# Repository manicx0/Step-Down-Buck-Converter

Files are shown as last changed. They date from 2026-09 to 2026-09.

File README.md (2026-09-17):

# LM5116 Wide-Range Synchronous Buck Converter

A variable-output synchronous buck converter designed around the Texas Instruments
LM5116 controller, capable of delivering 3 V to ~41 V output at up to 8 A from
a 45 V input rail. Designed as an open-source hardware project for industrial,
bench-supply, and automotive applications.

> ⚠️ **Status: Work In Progress — not yet validated on hardware.**
> Schematic is complete and under review. PCB layout not yet started.

---

## Specifications

| Parameter | Value |
|---|---|
| Input Voltage | Up to 45 V |
| Output Voltage | 3 V – ~41 V (continuously variable) |
| Maximum Output Current | 8 A |
| Switching Frequency | ~200 kHz |
| Control Method | Emulated peak current mode |
| Topology | Synchronous Buck |
| Controller IC | Texas Instruments LM5116MH/NOPB |

---

## Key Design Decisions

### Variable Output
Output voltage is set by a feedback divider on the FB pin (pin 9).
RFB1 (R4 = 1.21 kΩ) is fixed. RFB2 is implemented as a 50 kΩ potentiometer (R3)
in series with a 1.78 kΩ fixed resistor (R30), which hard-limits the minimum
output to 3 V even when the pot is at 0 Ω.
VOUT = 1.215 V × (1 + RFB2 / RFB1)

At RFB2 = 1.78 kΩ → VOUT = 3.01 V (minimum)
At RFB2 = 51.78 kΩ → VOUT ≈ 53 V (capped by VIN in practice)

### Slope Compensation (RRAMP)
For output voltages above 7.5 V, the LM5116 datasheet (Section 7.2.2.16)
requires a resistor from the RAMP pin to VCC to add slope compensation and
prevent subharmonic oscillation. R15 = 120 kΩ is connected between
pin 5 (RAMP) and pin 16 (VCC), sized for a nominal output of ~24 V.

### Emulated Current Ramp Capacitor

CRAMP = (gm × L) / (A × RS)
= (5 µA/V × 18 µH) / (10 V/V × 10 mΩ)
= 900 pF → 1 nF COG selected (C3)

### MOSFET Selection
Both high-side (Q3) and low-side (Q4) use the Infineon BSC070N10NS5,
a 100 V / 70 mΩ N-channel MOSFET in a TO-252 package. The 100 V rating
provides adequate margin over the 45 V input accounting for switching
transients and ringing.

Key references from the LM5116 datasheet (SNVS499I):
- Section 6.3.6 — Ramp generator and RRAMP justification
- Section 7.2.2.11 — Output voltage divider equations
- Section 7.2.2.16 — Comprehensive equations for VOUT > 7.5 V
- Section 7.4 — Layout guidelines

---

## ⚠️ Warnings & Limitations

- Maximum output voltage is bounded by the 450 ns forced HO off-time:
  `VOUT_max = VIN × (1 − 450 ns × fSW)`. At 45 V input and 200 kHz,
  this is approximately 41 V — not a true 45 V output.
- VCCX (pin 17) must be connected to GND if the external bias feature
  is not used. Leaving it floating causes unpredictable VCC behavior.
- This design has not yet been validated on hardware.
  Use at your own risk in any safety-critical application.
- High voltage and high current. Always verify polarity of electrolytic
  output capacitors before powering on.

---

## Acknowledgements

- Texas Instruments LM5116 datasheet (SNVS499I) — design procedure
  and equations throughout Section 7
- TI WEBENCH Power Designer for cross-checking component values
- Infineon BSC070N10NS5 datasheet for MOSFET loss calculations

---

## License

This project is released under the **CERN Open Hardware Licence Version 2 –
Weakly Reciprocal (CERN-OHL-W-2.0)**.

You are free to study, modify, and distribute this hardware design.
If you distribute modified versions, you must use the same licence.

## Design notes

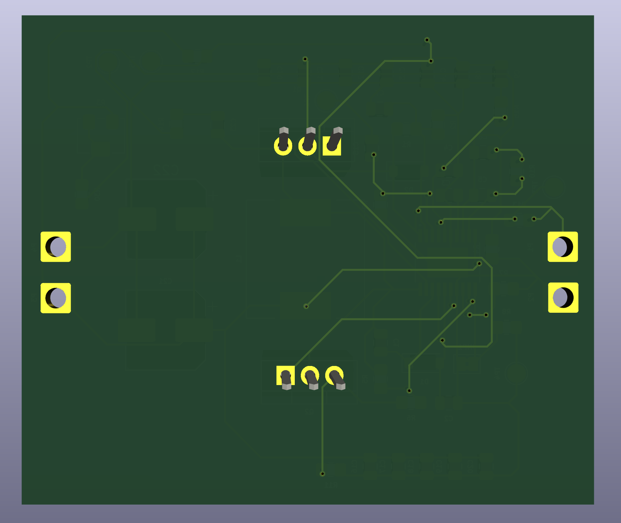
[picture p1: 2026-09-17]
hardware/exports/pcb-back.png

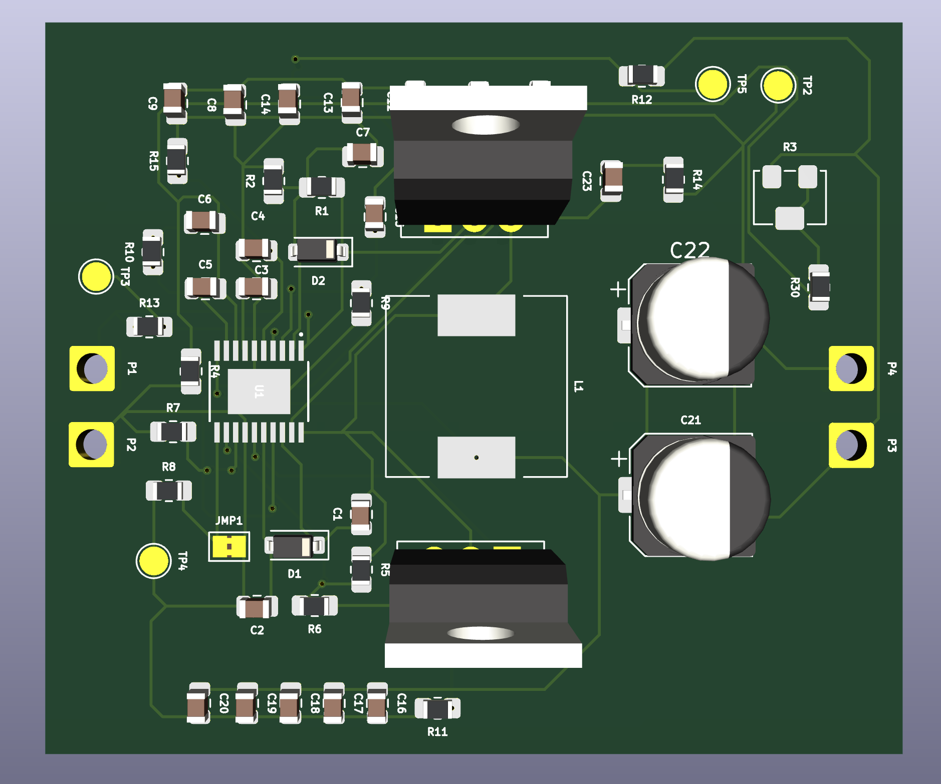
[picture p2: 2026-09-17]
hardware/exports/pcb-front.png

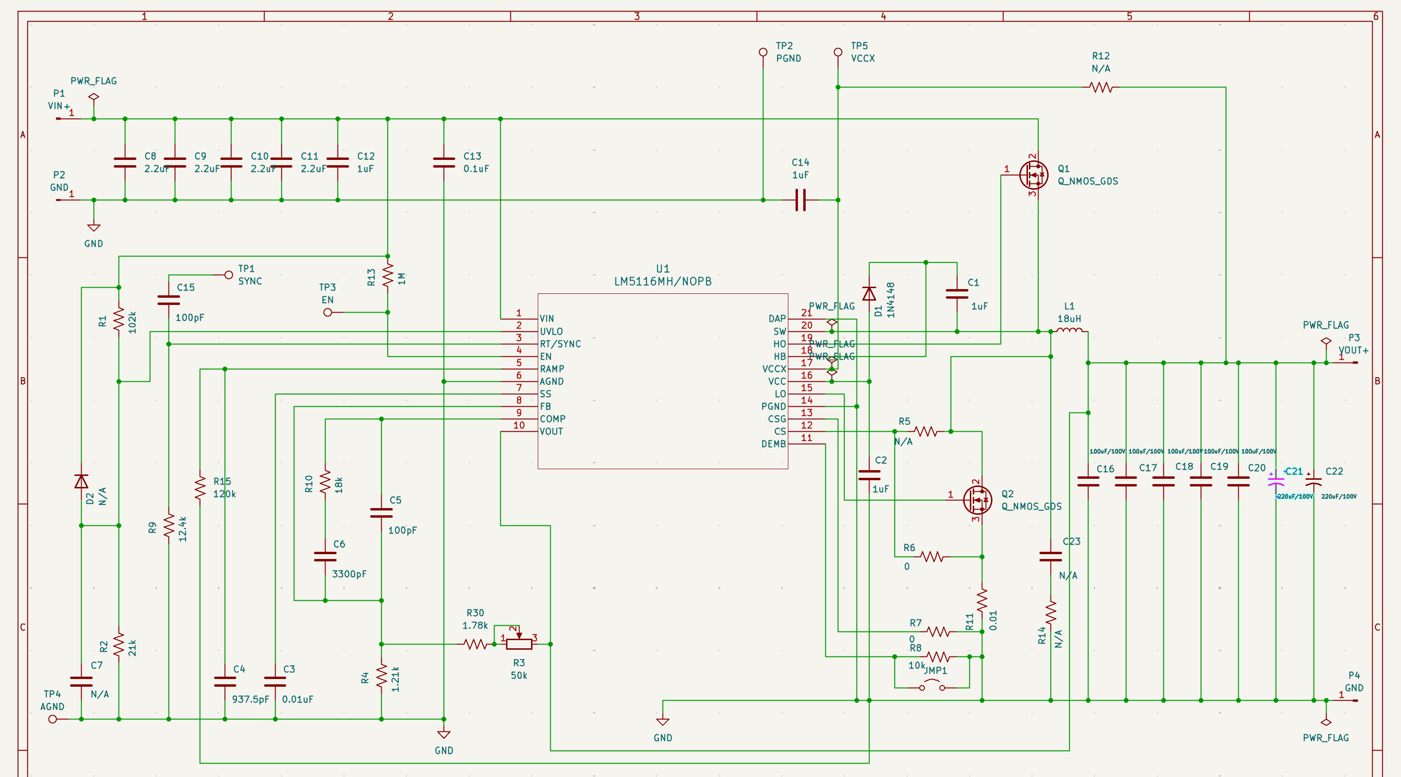
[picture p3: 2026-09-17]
hardware/exports/schematic.png

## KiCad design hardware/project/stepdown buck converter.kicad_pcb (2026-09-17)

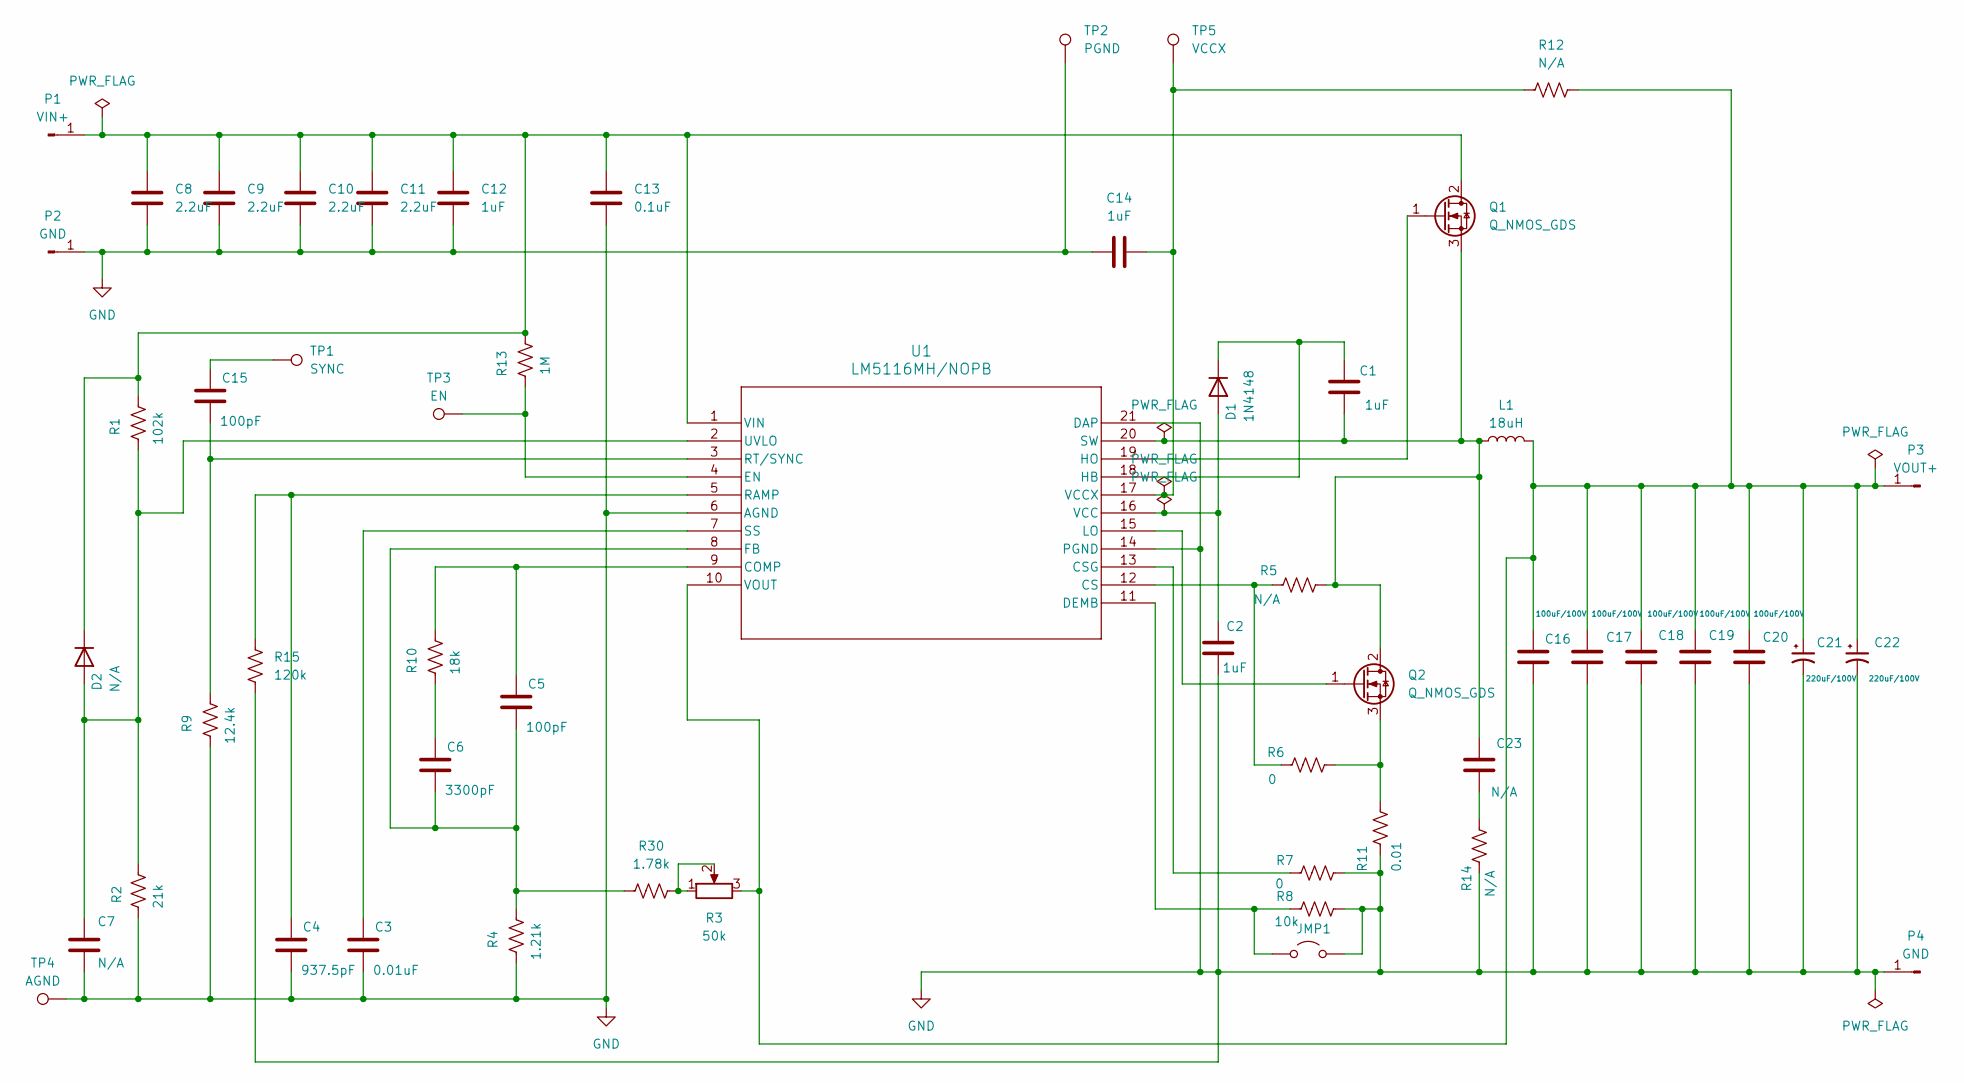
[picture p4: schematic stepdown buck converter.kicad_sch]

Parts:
C1, C2, C12, C14: 1uF; C_0805_2012Metric
C3: 0.01uF; C_0805_2012Metric
C4: 937.5pF; C_0805_2012Metric
C5, C15: 100pF; C_0805_2012Metric
C6: 3300pF; C_0805_2012Metric
C7, C23: N/A; C_0805_2012Metric
C8, C9, C10, C11: 2.2uF; C_0805_2012Metric
C13: 0.1uF; C_0805_2012Metric
C16, C17, C18, C19, C20: 100uF/100V; C_0805_2012Metric
C21, C22: 220uF/100V; CP_Elec_8x5.4
D1: 1N4148; D_SOD-123
D2: N/A; D_SOD-123
JMP1: SolderJumper-2_P1.3mm_Bridged2Bar_Pad1.0x1.5mm
L1: 18uH; L_12x12mm_H6mm
P1: VIN+; SolderWire-1.5sqmm_1x01_D1.7mm_OD3mm
P2, P4: GND; SolderWire-1.5sqmm_1x01_D1.7mm_OD3mm
P3: VOUT+; SolderWire-1.5sqmm_1x01_D1.7mm_OD3mm
Q1, Q2: Q_NMOS_GDS; TO-220-3_Vertical
R1: 102k; R_0805_2012Metric_Pad1.20x1.40mm_HandSolder
R2: 21k; R_0805_2012Metric_Pad1.20x1.40mm_HandSolder
R3: 50k; Potentiometer_Bourns_3214W_Vertical
R4: 1.21k; R_0805_2012Metric_Pad1.20x1.40mm_HandSolder
R5, R12, R14: N/A; R_0805_2012Metric_Pad1.20x1.40mm_HandSolder
R6, R7: 0; R_0805_2012Metric_Pad1.20x1.40mm_HandSolder
R8: 10k; R_0805_2012Metric_Pad1.20x1.40mm_HandSolder
R9: 12.4k; R_0805_2012Metric_Pad1.20x1.40mm_HandSolder
R10: 18k; R_0805_2012Metric_Pad1.20x1.40mm_HandSolder
R11: 0.01; R_0805_2012Metric_Pad1.20x1.40mm_HandSolder
R13: 1M; R_0805_2012Metric_Pad1.20x1.40mm_HandSolder
R15: 120k; R_0805_2012Metric_Pad1.20x1.40mm_HandSolder
R30: 1.78k; R_0805_2012Metric_Pad1.20x1.40mm_HandSolder
TP1: SYNC; TestPoint_Pad_D2.0mm
TP2: PGND; TestPoint_Pad_D2.0mm
TP3: EN; TestPoint_Pad_D2.0mm
TP4: AGND; TestPoint_Pad_D2.0mm
TP5: VCCX; TestPoint_Pad_D2.0mm
U1: LM5116MH/NOPB; MXA20A_TEX

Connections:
GND: C2.2, C3.2, C4.2, C7.2, C8.1, C9.1, C10.1, C11.1, C12.1, C13.1, C14.1, C16.2, C17.2, C18.2, C19.2, C20.2, C21.2, C22.2, JMP1.2 (B), P2.1 (Pin_1_1), P4.1 (Pin_1_1), R2.2, R4.2, R7.1, R8.1, R9.2, R11.2, R14.2, R15.2, TP2.1 (1_1), TP4.1 (1_1), U1.6 (AGND), U1.14 (PGND), U1.21 (DAP)
unnamed: C6.1, R10.2
unnamed: C15.1, TP1.1 (1_1)
unnamed: C23.2, R14.1
unnamed: C2.1, D1.2 (A), U1.16 (VCC)
unnamed: C1.1, D1.1 (K), U1.18 (HB)
unnamed: C7.1, D2.2 (A), R1.2, R2.1, U1.2 (UVLO)
unnamed: C8.2, C9.2, C10.2, C11.2, C12.2, C13.2, D2.1 (K), P1.1 (Pin_1_1), Q1.2 (D), R1.1, R13.1, U1.1 (VIN)
unnamed: JMP1.1 (A), R8.2, U1.11 (DEMB)
unnamed: C16.1, C17.1, C18.1, C19.1, C20.1, C21.1, C22.1, L1.2, P3.1 (Pin_1_1), R3.3, R12.1, U1.10 (VOUT)
unnamed: Q1.1 (G), U1.19 (HO)
unnamed: C1.2, C23.1, L1.1, Q1.3 (S), Q2.2 (D), R5.1, U1.20 (SW)
unnamed: Q2.1 (G), U1.15 (LO)
unnamed: Q2.3 (S), R6.1, R11.1
unnamed: R3.1, R3.2, R30.2
unnamed: C5.1, R10.1, U1.9 (COMP)
unnamed: R5.2, R6.2, U1.12 (CS)
unnamed: R7.2, U1.13 (CSG)
unnamed: R13.2, TP3.1 (1_1), U1.4 (EN)
unnamed: C5.2, C6.2, R4.1, R30.1, U1.8 (FB)
unnamed: C4.1, R15.1, U1.5 (RAMP)
unnamed: C15.2, R9.1, U1.3 (RT/SYNC)
unnamed: C3.1, U1.7 (SS)
unnamed: C14.2, R12.2, TP5.1 (1_1), U1.17 (VCCX)

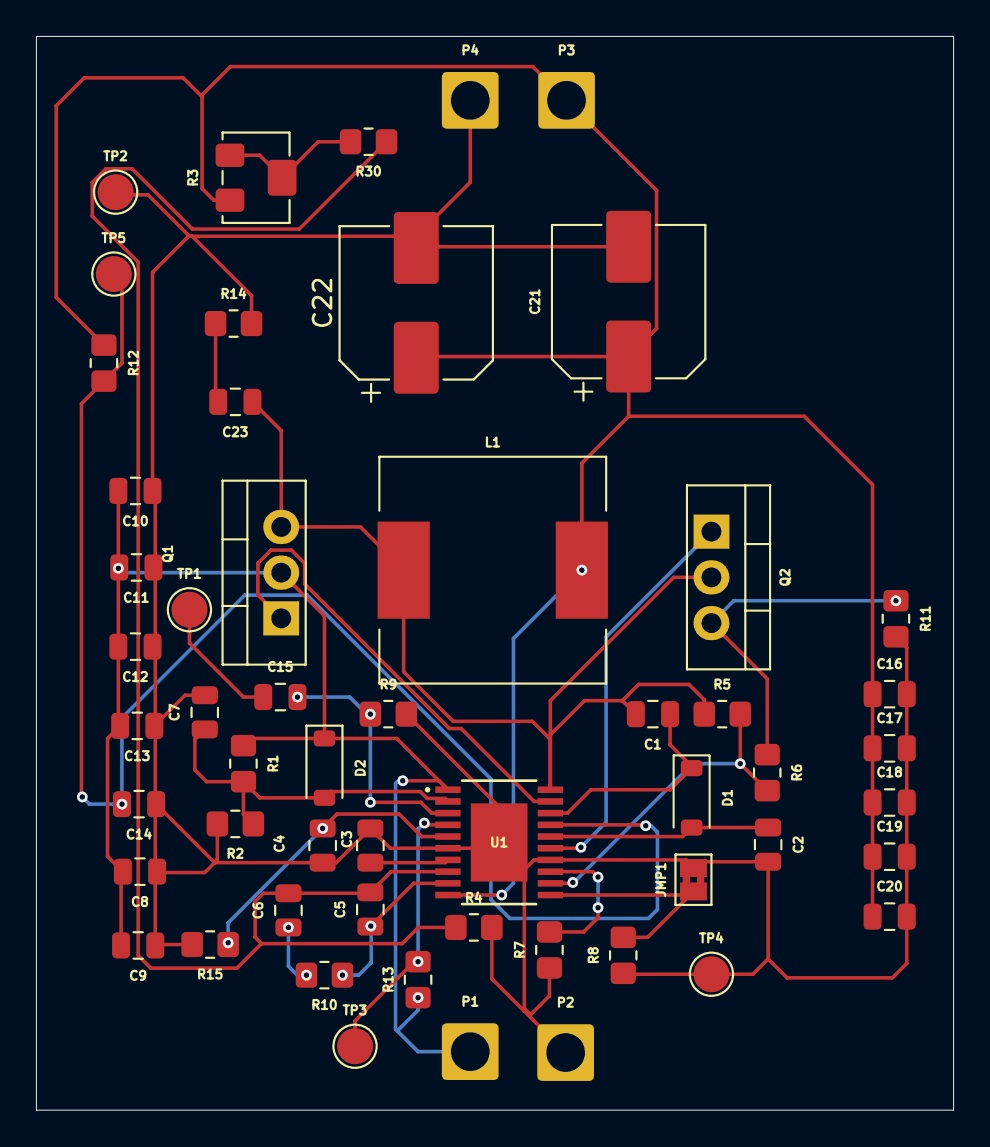
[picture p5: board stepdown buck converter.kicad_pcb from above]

Board: 2 copper layers, 51.0 x 59.7 mm, 55 parts (0 on the bottom side), 24 nets.
